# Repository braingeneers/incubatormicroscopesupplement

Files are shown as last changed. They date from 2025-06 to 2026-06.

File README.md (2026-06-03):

# incubatormicroscopesupplement

Supplemental material for the paper "A Modular In-Incubator Microscope for Longitudinal Live Cell Microscopy" by Drew Ehrlich, Yohei Rosen, Santhosh Arul, John Minnick, Seth Nicholson, Kateryna Voitiuk, Spencer Seiler, Anna Toledo, Samira Vera-Choqqueccota, Neil Doherty Jess Sevetson, Max McGlynn, Kivilcim Doganyigit, Maryam Moarefian, Sri Kurniawan, Mohammed A. Mostajo-Radji, Sofie R. Salama, Ethan Winkler, David Haussler, and Mircea Teodorescu.

## File Reference
CAD/CNC/ - 3D CNC parts for the microscopy system.

CAD/flatparts - CAD files for parts that can be milled on a CNC router

CAD/flatparts - CAD files for completed assemblies to be used as visual aids.

code/ - code for programming and operating the microscope in various configurations as shown in the manuscript

data/ - contains the source data for the thermal validation experiment described in Section 2.2.1 of the manuscript

The images for some of the experiments shown in the main manuscript can be found in a OSF repository at: https://osf.io/6wq7r

The contents of this repository are licensed under the Creative Commons CC BY NC license. More information here: https://creativecommons.org/licenses/by-nc/4.0/

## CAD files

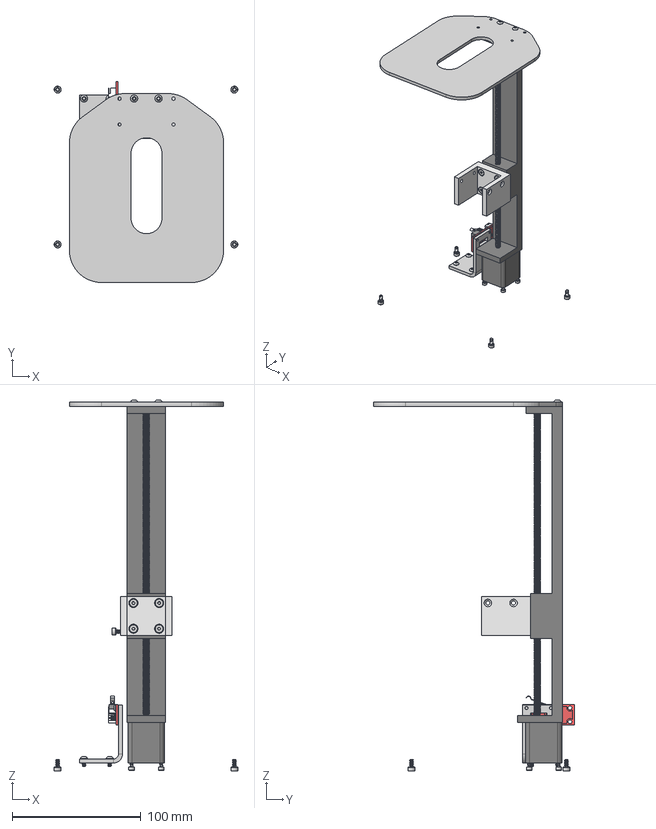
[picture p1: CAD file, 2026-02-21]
CAD/assemblies/zframeassembly.step
143.0 x 156.4 x 288.7 mm
6627T37_Position-Control DC Motor
97783A150_Fast-Travel Ultra-Precision Lead Screw x 3
91290A055_Black-Oxide Alloy Steel Socket Head Screw x 4
rail to alvium adapter 8mm base
Limit_switch
2cl_flou_assembly_topplate_fanct__1_ v2
91290A111_Black-Oxide Alloy Steel Socket Head Screw x 4
92095A181_Button Head Hex Drive Screw x 2
frameassem_1
L_endstopholder_zone (1)
92095A471_Button Head Hex Drive Screw x 2
92095A179_Button Head Hex Drive Screw x 4
91290A120_Black-Oxide Alloy Steel Socket Head Screw
92125A128_18-8 Stainless Steel Hex-Drive Flat Head Screw x 4

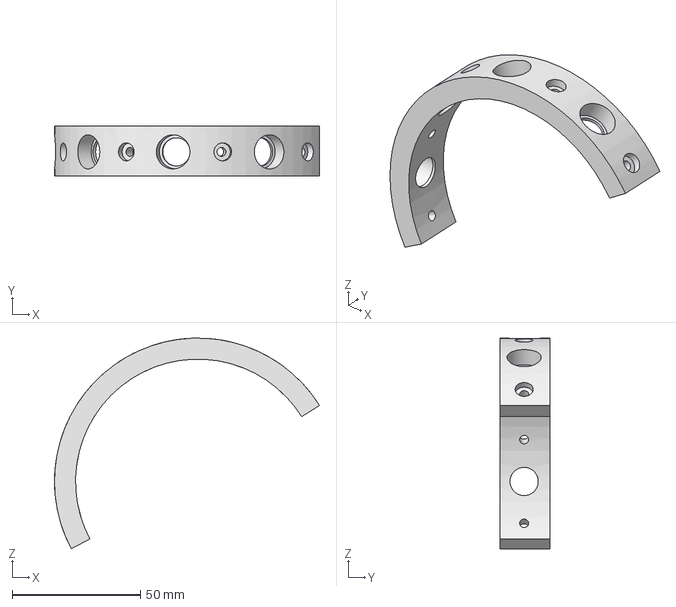
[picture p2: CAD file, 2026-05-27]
CAD/CNC/turret_excitationholder.step
103.2 x 19.4 x 82.0 mm

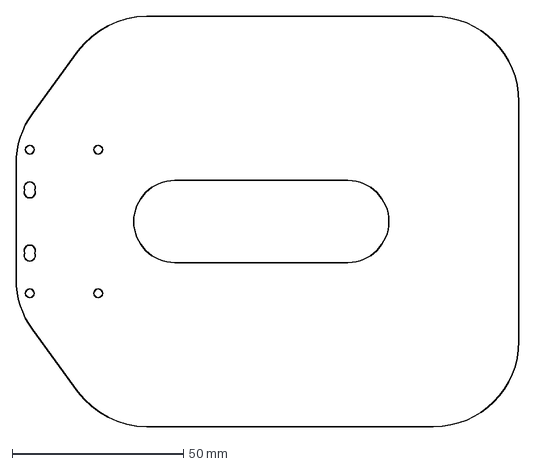
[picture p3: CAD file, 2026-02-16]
CAD/flatparts/flatslot_top_oval.dxf
147.0 x 120.0 mm

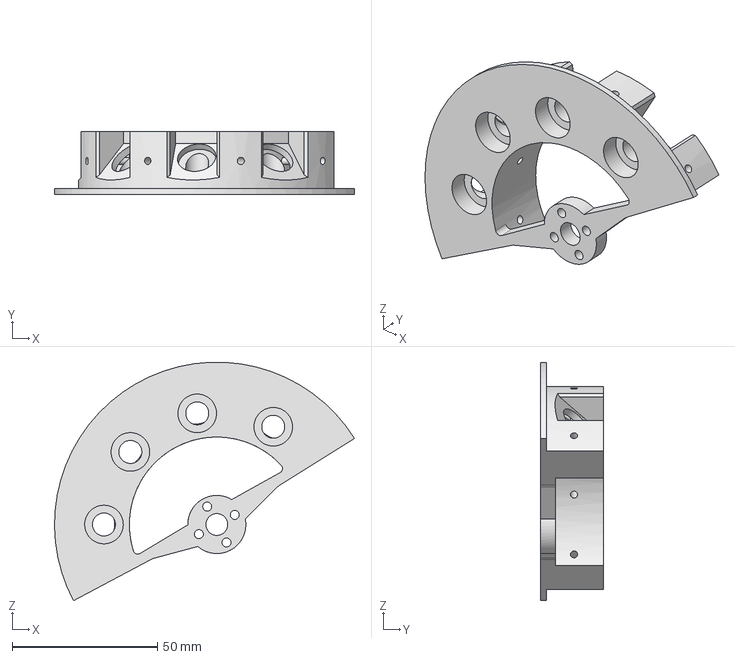
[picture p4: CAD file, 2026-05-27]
CAD/CNC/turret_dichroic_holder.step
103.2 x 21.5 x 82.0 mm

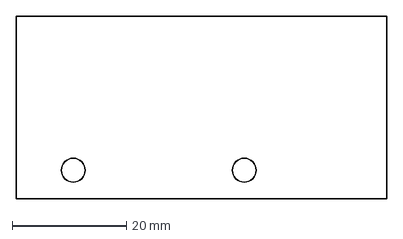
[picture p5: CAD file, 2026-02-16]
CAD/flatparts/endstop_hitter_long_xyz.dxf
65.0 x 32.0 mm

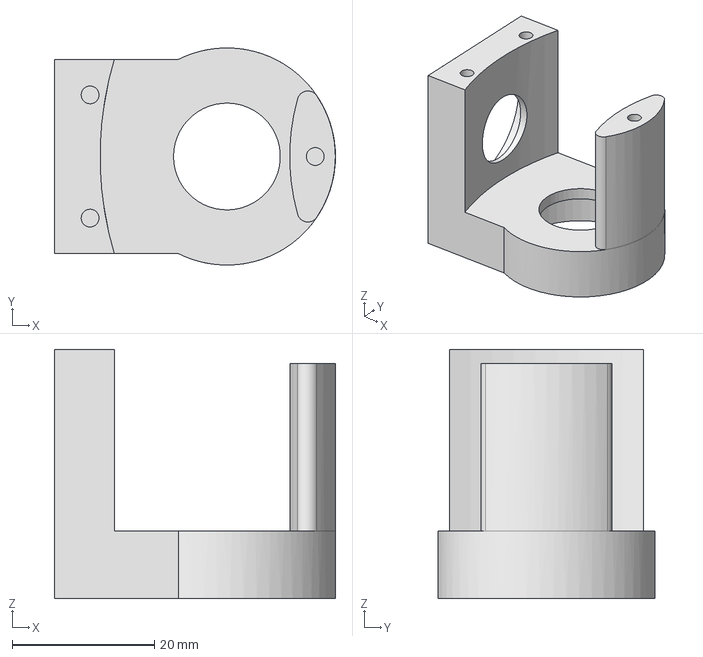
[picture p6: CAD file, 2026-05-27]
CAD/CNC/turret_outer_top_v2.step
39.5 x 30.5 x 35.0 mm

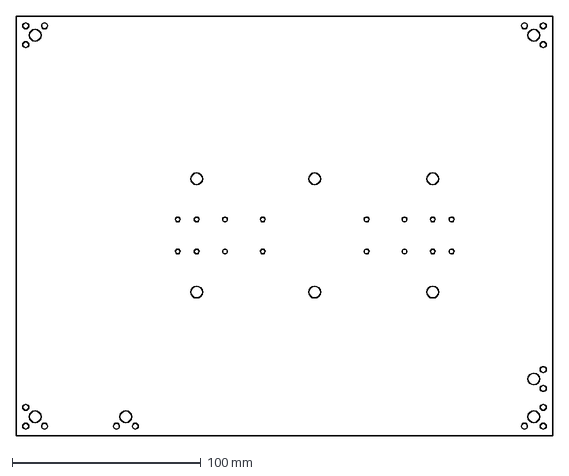
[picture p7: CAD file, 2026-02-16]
CAD/flatparts/bigbase_xyz.dxf
284.0 x 222.0 mm

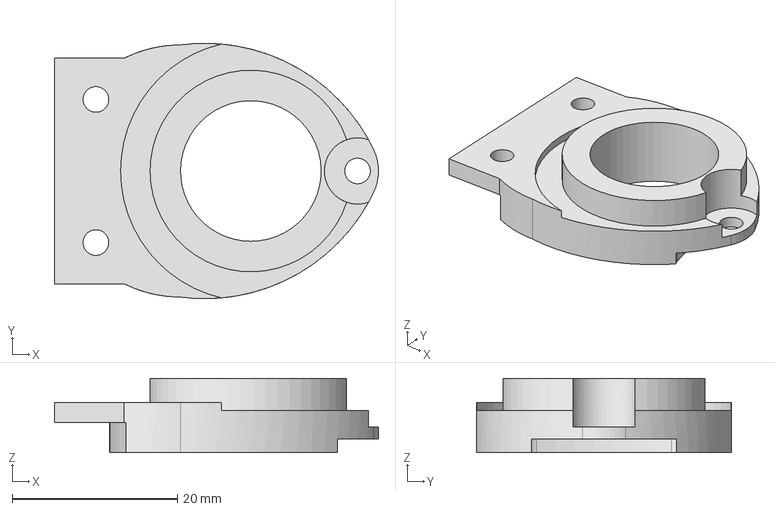
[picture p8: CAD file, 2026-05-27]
CAD/CNC/rotary_filter_barrel_bottom_v2.step
39.2 x 30.9 x 8.99 mm

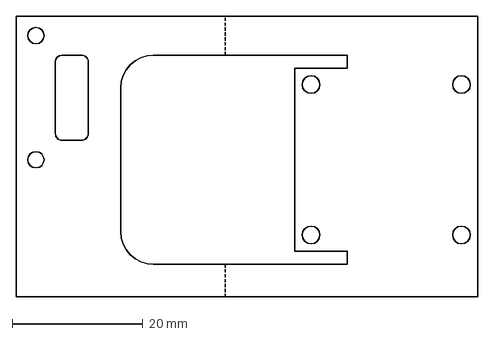
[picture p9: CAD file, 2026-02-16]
CAD/flatparts/xyz_end_218_rev.dxf
70.6 x 43.0 mm

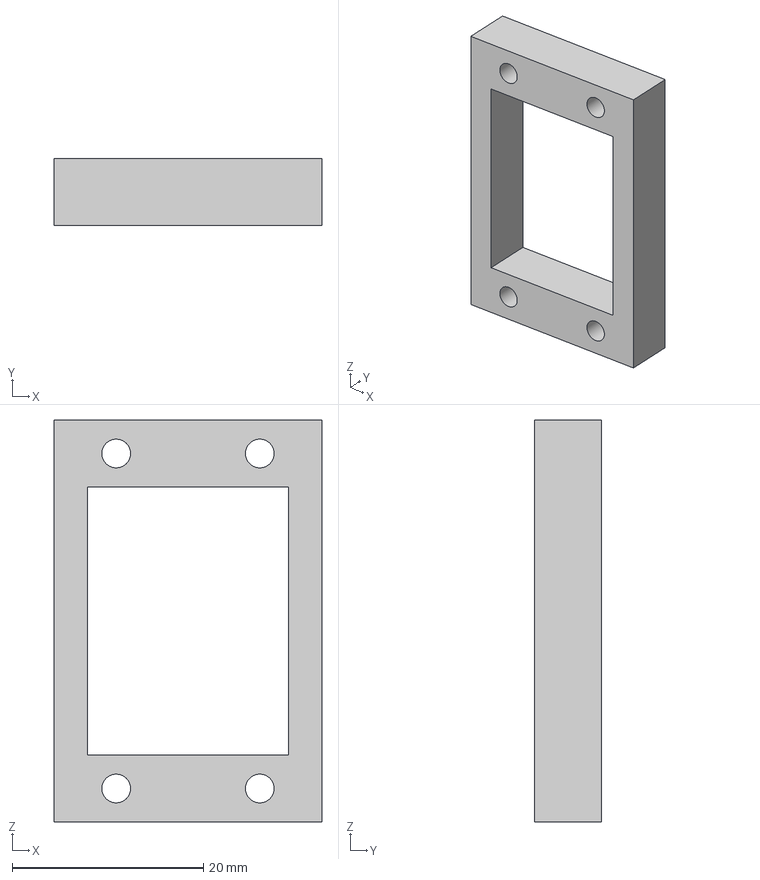
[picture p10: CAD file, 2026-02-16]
CAD/CNC/booster7mm.step
28.0 x 7.00 x 42.0 mm

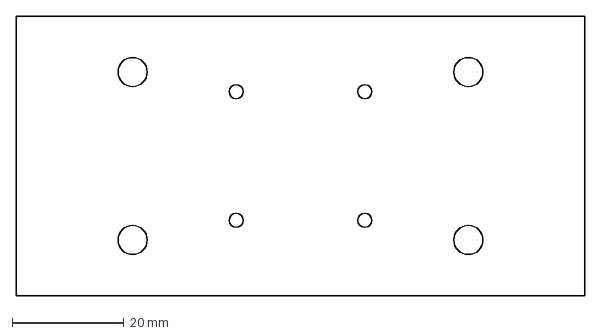
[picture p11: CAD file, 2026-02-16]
CAD/flatparts/midtop_longer_countersink_xyz.dxf
101.6 x 50.0 mm

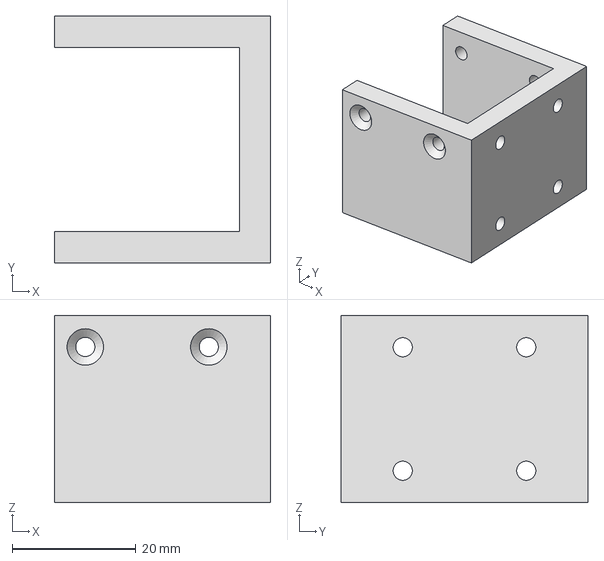
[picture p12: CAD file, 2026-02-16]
CAD/CNC/U_rail to alvium adapter.stp
35.0 x 40.0 x 30.3 mm

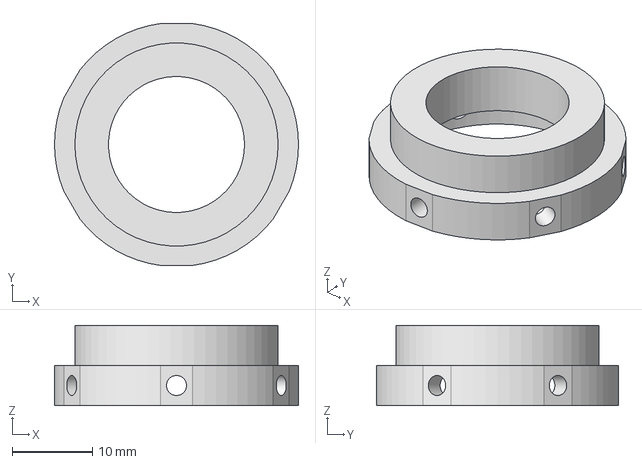
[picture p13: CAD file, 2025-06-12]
CAD/CNC/rotator to c-mount.stp
30.5 x 30.2 x 10.0 mm

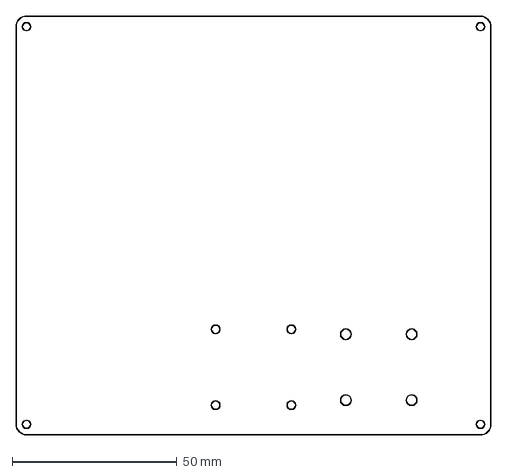
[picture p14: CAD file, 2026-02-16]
CAD/flatparts/microscope_base_z.dxf
144.1 x 127.0 mm

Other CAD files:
CAD/flatparts/frame_top_xyz.dwg
CAD/flatparts/midbot_countersink_xyz.dxf
CAD/flatparts/cam_to_turner_servo.dwg
CAD/flatparts/endstophitter_short_xyz.dxf
CAD/flatparts/endstopholder_Z.dxf
CAD/flatparts/xyz_frame_top_turner.dwg

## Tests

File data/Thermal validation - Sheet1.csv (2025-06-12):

reader date | reader time | interval | Servo | Ambient | Camera | Dish | unit
6/4/2025 0:57:57 | 0:57:57 | 5s | 38.7 | 33.8 | 44.1 | 25.2 | C
6/4/2025 0:58:02 | 0:58:02 | 5s | 38.7 | 33.8 | 44.1 | 25.2 | C
6/4/2025 0:58:07 | 0:58:07 | 5s | 38.7 | 33.8 | 44.1 | 25.2 | C
6/4/2025 0:58:12 | 0:58:12 | 5s | 38.7 | 33.8 | 44.1 | 25.8 | C
6/4/2025 0:58:17 | 0:58:17 | 5s | 38.7 | 34.4 | 44.1 | 25.8 | C
6/4/2025 0:58:22 | 0:58:22 | 5s | 38.7 | 34.4 | 44.1 | 25.8 | C
6/4/2025 0:58:27 | 0:58:27 | 5s | 38.7 | 34.4 | 44.1 | 25.8 | C
6/4/2025 0:58:32 | 0:58:32 | 5s | 38.7 | 34.4 | 44.1 | 25.8 | C
6/4/2025 0:58:37 | 0:58:37 | 5s | 38.7 | 34.4 | 44.1 | 25.9 | C
6/4/2025 0:58:42 | 0:58:42 | 5s | 38.7 | 34.6 | 44.1 | 25.9 | C
6/4/2025 0:58:47 | 0:58:47 | 5s | 38.7 | 34.6 | 44.1 | 26.5 | C
6/4/2025 0:58:52 | 0:58:52 | 5s | 38.7 | 34.6 | 44.1 | 26.5 | C
6/4/2025 0:58:57 | 0:58:57 | 5s | 38.7 | 34.7 | 44.1 | 26.5 | C
6/4/2025 0:59:02 | 0:59:02 | 5s | 38.7 | 34.7 | 44.1 | 26.5 | C
6/4/2025 0:59:07 | 0:59:07 | 5s | 38.7 | 34.7 | 44.1 | 26.5 | C
6/4/2025 0:59:12 | 0:59:12 | 5s | 38.7 | 35.2 | 44.1 | 26.7 | C
6/4/2025 0:59:17 | 0:59:17 | 5s | 38.7 | 35.2 | 44.1 | 26.7 | C
6/4/2025 0:59:22 | 0:59:22 | 5s | 38.7 | 35.2 | 44.1 | 26.7 | C
6/4/2025 0:59:27 | 0:59:27 | 5s | 38.7 | 35.2 | 44.1 | 26.8 | C
6/4/2025 0:59:32 | 0:59:32 | 5s | 38.7 | 35.2 | 44.1 | 27.3 | C
6/4/2025 0:59:37 | 0:59:37 | 5s | 38.7 | 35.2 | 44.1 | 27.3 | C
6/4/2025 0:59:42 | 0:59:42 | 5s | 38.7 | 35.2 | 44.1 | 27.3 | C
6/4/2025 0:59:47 | 0:59:47 | 5s | 38.7 | 35.2 | 44.1 | 27.3 | C
6/4/2025 0:59:52 | 0:59:52 | 5s | 38.7 | 35.2 | 44.1 | 27.3 | C
6/4/2025 0:59:57 | 0:59:57 | 5s | 38.7 | 35.3 | 44.2 | 27.4 | C
6/4/2025 1:00:02 | 1:00:02 | 5s | 38.7 | 35.3 | 44.2 | 27.4 | C
6/4/2025 1:00:07 | 1:00:07 | 5s | 38.7 | 35.3 | 44.2 | 27.4 | C
6/4/2025 1:00:12 | 1:00:12 | 5s | 38.7 | 35.3 | 44.2 | 27.6 | C
6/4/2025 1:00:17 | 1:00:17 | 5s | 38.7 | 35.3 | 44.2 | 27.6 | C
6/4/2025 1:00:22 | 1:00:22 | 5s | 38.7 | 35.3 | 44.2 | 27.6 | C
6/4/2025 1:00:27 | 1:00:27 | 5s | 38.8 | 35.4 | 44.2 | 27.7 | C
6/4/2025 1:00:32 | 1:00:32 | 5s | 38.8 | 35.4 | 44.2 | 27.7 | C
6/4/2025 1:00:37 | 1:00:37 | 5s | 38.8 | 35.4 | 44.2 | 27.7 | C
6/4/2025 1:00:42 | 1:00:42 | 5s | 38.8 | 35.4 | 44.2 | 27.8 | C
6/4/2025 1:00:47 | 1:00:47 | 5s | 38.8 | 35.5 | 44.2 | 27.8 | C
6/4/2025 1:00:52 | 1:00:52 | 5s | 38.8 | 35.5 | 44.2 | 27.8 | C
6/4/2025 1:00:57 | 1:00:57 | 5s | 38.8 | 35.6 | 44.2 | 28 | C
6/4/2025 1:01:02 | 1:01:02 | 5s | 38.8 | 35.6 | 44.2 | 28 | C
6/4/2025 1:01:07 | 1:01:07 | 5s | 38.8 | 35.6 | 44.2 | 28 | C
6/4/2025 1:01:12 | 1:01:12 | 5s | 38.8 | 35.7 | 44.2 | 28.1 | C
6/4/2025 1:01:17 | 1:01:17 | 5s | 38.8 | 35.7 | 44.2 | 28.1 | C
6/4/2025 1:01:22 | 1:01:22 | 5s | 38.8 | 35.7 | 44.2 | 28.1 | C
6/4/2025 1:01:27 | 1:01:27 | 5s | 38.8 | 35.7 | 44.2 | 28.2 | C
6/4/2025 1:01:32 | 1:01:32 | 5s | 38.8 | 35.7 | 44.3 | 28.8 | C
6/4/2025 1:01:37 | 1:01:37 | 5s | 38.8 | 35.8 | 44.3 | 28.8 | C
6/4/2025 1:01:42 | 1:01:42 | 5s | 38.8 | 35.8 | 44.3 | 28.8 | C
6/4/2025 1:01:47 | 1:01:47 | 5s | 38.8 | 35.8 | 44.3 | 28.8 | C
6/4/2025 1:01:52 | 1:01:52 | 5s | 38.9 | 35.8 | 44.3 | 28.8 | C
6/4/2025 1:01:57 | 1:01:57 | 5s | 38.9 | 35.8 | 44.3 | 28.9 | C
6/4/2025 1:02:02 | 1:02:02 | 5s | 38.9 | 35.9 | 44.3 | 28.9 | C
6/4/2025 1:02:07 | 1:02:07 | 5s | 38.9 | 35.9 | 44.3 | 28.9 | C
6/4/2025 1:02:12 | 1:02:12 | 5s | 38.9 | 35.9 | 44.3 | 29.1 | C
6/4/2025 1:02:17 | 1:02:17 | 5s | 38.9 | 35.9 | 44.3 | 29.1 | C
6/4/2025 1:02:22 | 1:02:22 | 5s | 38.9 | 35.9 | 44.3 | 29.1 | C
6/4/2025 1:02:27 | 1:02:27 | 5s | 38.9 | 36.1 | 44.3 | 29.2 | C
6/4/2025 1:02:32 | 1:02:32 | 5s | 38.9 | 36.1 | 44.3 | 29.2 | C
6/4/2025 1:02:37 | 1:02:37 | 5s | 38.9 | 36.1 | 44.3 | 29.2 | C
6/4/2025 1:02:42 | 1:02:42 | 5s | 38.9 | 36.1 | 44.3 | 29.8 | C
6/4/2025 1:02:47 | 1:02:47 | 5s | 38.9 | 36.1 | 44.3 | 29.8 | C
6/4/2025 1:02:52 | 1:02:52 | 5s | 38.9 | 36.1 | 44.3 | 29.8 | C
6/4/2025 1:02:57 | 1:02:57 | 5s | 38.9 | 36.2 | 44.4 | 29.8 | C
6/4/2025 1:03:02 | 1:03:02 | 5s | 38.9 | 36.2 | 44.4 | 29.8 | C
6/4/2025 1:03:07 | 1:03:07 | 5s | 38.9 | 36.2 | 44.4 | 29.8 | C
6/4/2025 1:03:12 | 1:03:12 | 5s | 38.9 | 36.2 | 44.4 | 29.8 | C
6/4/2025 1:03:17 | 1:03:17 | 5s | 38.9 | 36.2 | 44.4 | 29.9 | C
6/4/2025 1:03:22 | 1:03:22 | 5s | 38.9 | 36.2 | 44.4 | 30 | C
6/4/2025 1:03:27 | 1:03:27 | 5s | 38.9 | 36.2 | 44.4 | 30 | C
6/4/2025 1:03:32 | 1:03:32 | 5s | 39 | 36.3 | 44.4 | 30.1 | C
6/4/2025 1:03:37 | 1:03:37 | 5s | 39 | 36.3 | 44.4 | 30.1 | C
6/4/2025 1:03:42 | 1:03:42 | 5s | 39 | 36.3 | 44.4 | 30.1 | C
6/4/2025 1:03:47 | 1:03:47 | 5s | 39 | 36.3 | 44.4 | 30.2 | C
6/4/2025 1:03:52 | 1:03:52 | 5s | 39 | 36.3 | 44.4 | 30.2 | C
6/4/2025 1:03:57 | 1:03:57 | 5s | 39 | 36.3 | 44.4 | 30.8 | C
6/4/2025 1:04:02 | 1:04:02 | 5s | 39 | 36.4 | 44.4 | 30.8 | C
6/4/2025 1:04:07 | 1:04:07 | 5s | 39 | 36.4 | 44.4 | 30.8 | C
6/4/2025 1:04:12 | 1:04:12 | 5s | 39.1 | 36.4 | 44.4 | 30.8 | C
6/4/2025 1:04:17 | 1:04:17 | 5s | 39.1 | 36.4 | 44.4 | 30.8 | C
6/4/2025 1:04:22 | 1:04:22 | 5s | 39.1 | 36.5 | 44.5 | 30.8 | C
6/4/2025 1:04:27 | 1:04:27 | 5s | 39.1 | 36.5 | 44.5 | 30.8 | C
6/4/2025 1:04:32 | 1:04:32 | 5s | 39.1 | 36.5 | 44.5 | 30.8 | C
6/4/2025 1:04:37 | 1:04:37 | 5s | 39.1 | 36.5 | 44.5 | 30.9 | C
6/4/2025 1:04:42 | 1:04:42 | 5s | 39.1 | 36.5 | 44.5 | 30.9 | C
6/4/2025 1:04:47 | 1:04:47 | 5s | 39.1 | 36.5 | 44.5 | 30.9 | C
6/4/2025 1:04:52 | 1:04:52 | 5s | 39.1 | 36.5 | 44.5 | 30.9 | C
6/4/2025 1:04:57 | 1:04:57 | 5s | 39.1 | 36.6 | 44.5 | 31 | C
6/4/2025 1:05:02 | 1:05:02 | 5s | 39.1 | 36.6 | 44.5 | 31 | C
6/4/2025 1:05:07 | 1:05:07 | 5s | 39.1 | 36.6 | 44.6 | 31 | C
6/4/2025 1:05:12 | 1:05:12 | 5s | 39.1 | 36.6 | 44.6 | 31.1 | C
6/4/2025 1:05:17 | 1:05:17 | 5s | 39.1 | 36.6 | 44.6 | 31.2 | C
6/4/2025 1:05:22 | 1:05:22 | 5s | 39.1 | 36.6 | 44.6 | 31.2 | C
6/4/2025 1:05:27 | 1:05:27 | 5s | 39.1 | 36.6 | 44.6 | 31.2 | C
6/4/2025 1:05:32 | 1:05:32 | 5s | 39.1 | 36.6 | 44.6 | 31.2 | C
6/4/2025 1:05:37 | 1:05:37 | 5s | 39.1 | 36.6 | 44.6 | 31.3 | C
6/4/2025 1:05:42 | 1:05:42 | 5s | 39.2 | 36.6 | 44.6 | 31.3 | C
6/4/2025 1:05:47 | 1:05:47 | 5s | 39.2 | 36.6 | 44.6 | 31.3 | C
6/4/2025 1:05:52 | 1:05:52 | 5s | 39.2 | 36.6 | 44.6 | 31.3 | C
6/4/2025 1:05:57 | 1:05:57 | 5s | 39.2 | 36.6 | 44.6 | 31.4 | C
6/4/2025 1:06:02 | 1:06:02 | 5s | 39.2 | 36.7 | 44.6 | 31.4 | C
6/4/2025 1:06:07 | 1:06:07 | 5s | 39.2 | 36.7 | 44.6 | 31.4 | C
6/4/2025 1:06:12 | 1:06:12 | 5s | 39.2 | 36.7 | 44.6 | 31.5 | C
6/4/2025 1:06:17 | 1:06:17 | 5s | 39.2 | 36.7 | 44.6 | 31.6 | C
6/4/2025 1:06:22 | 1:06:22 | 5s | 39.2 | 36.7 | 44.6 | 31.6 | C
6/4/2025 1:06:27 | 1:06:27 | 5s | 39.2 | 36.7 | 44.7 | 31.6 | C
6/4/2025 1:06:32 | 1:06:32 | 5s | 39.2 | 36.7 | 44.7 | 31.7 | C
6/4/2025 1:06:37 | 1:06:37 | 5s | 39.2 | 36.7 | 44.7 | 31.7 | C
6/4/2025 1:06:42 | 1:06:42 | 5s | 39.2 | 36.7 | 44.7 | 31.7 | C
6/4/2025 1:06:47 | 1:06:47 | 5s | 39.2 | 36.7 | 44.7 | 31.8 | C
6/4/2025 1:06:52 | 1:06:52 | 5s | 39.2 | 36.7 | 44.7 | 31.8 | C
6/4/2025 1:06:57 | 1:06:57 | 5s | 39.2 | 36.7 | 44.7 | 31.8 | C
6/4/2025 1:07:02 | 1:07:02 | 5s | 39.3 | 36.8 | 44.7 | 31.9 | C
6/4/2025 1:07:07 | 1:07:07 | 5s | 39.3 | 36.8 | 44.7 | 31.9 | C
6/4/2025 1:07:12 | 1:07:12 | 5s | 39.3 | 36.8 | 44.7 | 31.9 | C
6/4/2025 1:07:17 | 1:07:17 | 5s | 39.3 | 36.8 | 44.7 | 31.9 | C
6/4/2025 1:07:22 | 1:07:22 | 5s | 39.3 | 36.8 | 44.7 | 32.1 | C
6/4/2025 1:07:27 | 1:07:27 | 5s | 39.3 | 36.8 | 44.7 | 32.1 | C
6/4/2025 1:07:32 | 1:07:32 | 5s | 39.3 | 36.8 | 44.7 | 32.1 | C
6/4/2025 1:07:37 | 1:07:37 | 5s | 39.3 | 36.8 | 44.7 | 32.2 | C
6/4/2025 1:07:42 | 1:07:42 | 5s | 39.3 | 36.8 | 44.7 | 32.2 | C
6/4/2025 1:07:47 | 1:07:47 | 5s | 39.3 | 36.8 | 44.8 | 32.2 | C
6/4/2025 1:07:52 | 1:07:52 | 5s | 39.3 | 36.8 | 44.8 | 32.3 | C
6/4/2025 1:07:57 | 1:07:57 | 5s | 39.3 | 36.8 | 44.8 | 32.3 | C
6/4/2025 1:08:02 | 1:08:02 | 5s | 39.3 | 36.8 | 44.8 | 32.3 | C
6/4/2025 1:08:07 | 1:08:07 | 5s | 39.3 | 36.8 | 44.8 | 32.4 | C
6/4/2025 1:08:12 | 1:08:12 | 5s | 39.4 | 36.8 | 44.8 | 32.4 | C
6/4/2025 1:08:17 | 1:08:17 | 5s | 39.4 | 36.8 | 44.8 | 32.4 | C
6/4/2025 1:08:22 | 1:08:22 | 5s | 39.4 | 36.8 | 44.8 | 32.6 | C
6/4/2025 1:08:27 | 1:08:27 | 5s | 39.4 | 36.8 | 44.8 | 32.6 | C
6/4/2025 1:08:32 | 1:08:32 | 5s | 39.4 | 36.8 | 44.8 | 32.6 | C
6/4/2025 1:08:37 | 1:08:37 | 5s | 39.4 | 36.9 | 44.8 | 32.6 | C
6/4/2025 1:08:42 | 1:08:42 | 5s | 39.4 | 36.9 | 44.8 | 32.7 | C
6/4/2025 1:08:47 | 1:08:47 | 5s | 39.4 | 36.9 | 44.8 | 32.7 | C
6/4/2025 1:08:52 | 1:08:52 | 5s | 39.4 | 36.9 | 44.8 | 32.7 | C
6/4/2025 1:08:57 | 1:08:57 | 5s | 39.4 | 36.9 | 44.8 | 32.7 | C
6/4/2025 1:09:02 | 1:09:02 | 5s | 39.4 | 36.9 | 44.8 | 32.8 | C
6/4/2025 1:09:07 | 1:09:07 | 5s | 39.4 | 36.9 | 44.8 | 32.8 | C
6/4/2025 1:09:12 | 1:09:12 | 5s | 39.4 | 36.9 | 44.8 | 32.8 | C
6/4/2025 1:09:17 | 1:09:17 | 5s | 39.4 | 36.9 | 44.9 | 32.8 | C
6/4/2025 1:09:22 | 1:09:22 | 5s | 39.5 | 36.9 | 44.9 | 32.9 | C
6/4/2025 1:09:27 | 1:09:27 | 5s | 39.5 | 36.9 | 44.9 | 32.9 | C
6/4/2025 1:09:32 | 1:09:32 | 5s | 39.5 | 36.9 | 44.9 | 32.9 | C
6/4/2025 1:09:37 | 1:09:37 | 5s | 39.5 | 36.9 | 44.9 | 32.9 | C
6/4/2025 1:09:42 | 1:09:42 | 5s | 39.5 | 36.9 | 44.9 | 33.1 | C
6/4/2025 1:09:47 | 1:09:47 | 5s | 39.5 | 36.9 | 44.9 | 33.1 | C
6/4/2025 1:09:52 | 1:09:52 | 5s | 39.5 | 36.9 | 44.9 | 33.1 | C
6/4/2025 1:09:57 | 1:09:57 | 5s | 39.6 | 36.9 | 44.9 | 33.1 | C
6/4/2025 1:10:02 | 1:10:02 | 5s | 39.6 | 36.9 | 44.9 | 33.1 | C
6/4/2025 1:10:07 | 1:10:07 | 5s | 39.6 | 36.9 | 44.9 | 33.2 | C
6/4/2025 1:10:12 | 1:10:12 | 5s | 39.6 | 36.9 | 44.9 | 33.2 | C
6/4/2025 1:10:17 | 1:10:17 | 5s | 39.6 | 36.9 | 44.9 | 33.2 | C
6/4/2025 1:10:22 | 1:10:22 | 5s | 39.6 | 36.9 | 44.9 | 33.2 | C
6/4/2025 1:10:27 | 1:10:27 | 5s | 39.6 | 36.9 | 44.9 | 33.2 | C
6/4/2025 1:10:32 | 1:10:32 | 5s | 39.6 | 36.9 | 44.9 | 33.3 | C
6/4/2025 1:10:37 | 1:10:37 | 5s | 39.6 | 37 | 44.9 | 33.3 | C
6/4/2025 1:10:42 | 1:10:42 | 5s | 39.6 | 37 | 44.9 | 33.3 | C
6/4/2025 1:10:47 | 1:10:47 | 5s | 39.6 | 37 | 45 | 33.4 | C
6/4/2025 1:10:52 | 1:10:52 | 5s | 39.6 | 37 | 45 | 33.4 | C
6/4/2025 1:10:57 | 1:10:57 | 5s | 39.6 | 37 | 45 | 33.5 | C
6/4/2025 1:11:02 | 1:11:02 | 5s | 39.6 | 37 | 45 | 33.5 | C
6/4/2025 1:11:07 | 1:11:07 | 5s | 39.6 | 37 | 45 | 33.5 | C
6/4/2025 1:11:12 | 1:11:12 | 5s | 39.7 | 37 | 45 | 33.5 | C
6/4/2025 1:11:17 | 1:11:17 | 5s | 39.7 | 37 | 45 | 33.5 | C
6/4/2025 1:11:22 | 1:11:22 | 5s | 39.7 | 37 | 45 | 33.5 | C
6/4/2025 1:11:27 | 1:11:27 | 5s | 39.7 | 37 | 45 | 33.6 | C
6/4/2025 1:11:32 | 1:11:32 | 5s | 39.7 | 37 | 45 | 33.6 | C
6/4/2025 1:11:37 | 1:11:37 | 5s | 39.7 | 37 | 45.1 | 33.6 | C
6/4/2025 1:11:42 | 1:11:42 | 5s | 39.7 | 37 | 45.1 | 33.6 | C
6/4/2025 1:11:47 | 1:11:47 | 5s | 39.7 | 37 | 45.1 | 33.7 | C
6/4/2025 1:11:52 | 1:11:52 | 5s | 39.7 | 37 | 45.1 | 33.7 | C
6/4/2025 1:11:57 | 1:11:57 | 5s | 39.7 | 37 | 45.1 | 33.8 | C
6/4/2025 1:12:02 | 1:12:02 | 5s | 39.7 | 37 | 45.1 | 33.8 | C
6/4/2025 1:12:07 | 1:12:07 | 5s | 39.7 | 37 | 45.1 | 33.8 | C
6/4/2025 1:12:12 | 1:12:12 | 5s | 39.7 | 37.1 | 45.1 | 33.8 | C
6/4/2025 1:12:17 | 1:12:17 | 5s | 39.7 | 37.1 | 45.1 | 33.8 | C
6/4/2025 1:12:22 | 1:12:22 | 5s | 39.7 | 37.1 | 45.1 | 33.8 | C
6/4/2025 1:12:27 | 1:12:27 | 5s | 39.7 | 37.1 | 45.1 | 33.9 | C
6/4/2025 1:12:32 | 1:12:32 | 5s | 39.7 | 37.1 | 45.1 | 33.9 | C
6/4/2025 1:12:37 | 1:12:37 | 5s | 39.7 | 37.1 | 45.1 | 33.9 | C
6/4/2025 1:12:42 | 1:12:42 | 5s | 39.8 | 37.1 | 45.1 | 33.9 | C
6/4/2025 1:12:47 | 1:12:47 | 5s | 39.8 | 37.1 | 45.1 | 33.9 | C
6/4/2025 1:12:52 | 1:12:52 | 5s | 39.8 | 37.1 | 45.1 | 33.9 | C
6/4/2025 1:12:57 | 1:12:57 | 5s | 39.8 | 37.1 | 45.1 | 33.9 | C
6/4/2025 1:13:02 | 1:13:02 | 5s | 39.8 | 37.1 | 45.1 | 34.1 | C
6/4/2025 1:13:07 | 1:13:07 | 5s | 39.8 | 37.1 | 45.2 | 34.1 | C
6/4/2025 1:13:12 | 1:13:12 | 5s | 39.8 | 37.1 | 45.2 | 34.1 | C
6/4/2025 1:13:17 | 1:13:17 | 5s | 39.8 | 37.1 | 45.2 | 34.1 | C
6/4/2025 1:13:22 | 1:13:22 | 5s | 39.8 | 37.1 | 45.2 | 34.1 | C
6/4/2025 1:13:27 | 1:13:27 | 5s | 39.8 | 37.1 | 45.2 | 34.1 | C
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

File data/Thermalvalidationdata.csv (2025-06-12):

reader date | reader time | interval | Servo | Ambient | Camera | Dish | unit
6/4/2025 0:57:57 | 0:57:57 | 5s | 38.7 | 33.8 | 44.1 | 25.2 | C
6/4/2025 0:58:02 | 0:58:02 | 5s | 38.7 | 33.8 | 44.1 | 25.2 | C
6/4/2025 0:58:07 | 0:58:07 | 5s | 38.7 | 33.8 | 44.1 | 25.2 | C
6/4/2025 0:58:12 | 0:58:12 | 5s | 38.7 | 33.8 | 44.1 | 25.8 | C
6/4/2025 0:58:17 | 0:58:17 | 5s | 38.7 | 34.4 | 44.1 | 25.8 | C
6/4/2025 0:58:22 | 0:58:22 | 5s | 38.7 | 34.4 | 44.1 | 25.8 | C
6/4/2025 0:58:27 | 0:58:27 | 5s | 38.7 | 34.4 | 44.1 | 25.8 | C
6/4/2025 0:58:32 | 0:58:32 | 5s | 38.7 | 34.4 | 44.1 | 25.8 | C
6/4/2025 0:58:37 | 0:58:37 | 5s | 38.7 | 34.4 | 44.1 | 25.9 | C
6/4/2025 0:58:42 | 0:58:42 | 5s | 38.7 | 34.6 | 44.1 | 25.9 | C
6/4/2025 0:58:47 | 0:58:47 | 5s | 38.7 | 34.6 | 44.1 | 26.5 | C
6/4/2025 0:58:52 | 0:58:52 | 5s | 38.7 | 34.6 | 44.1 | 26.5 | C
6/4/2025 0:58:57 | 0:58:57 | 5s | 38.7 | 34.7 | 44.1 | 26.5 | C
6/4/2025 0:59:02 | 0:59:02 | 5s | 38.7 | 34.7 | 44.1 | 26.5 | C
6/4/2025 0:59:07 | 0:59:07 | 5s | 38.7 | 34.7 | 44.1 | 26.5 | C
6/4/2025 0:59:12 | 0:59:12 | 5s | 38.7 | 35.2 | 44.1 | 26.7 | C
6/4/2025 0:59:17 | 0:59:17 | 5s | 38.7 | 35.2 | 44.1 | 26.7 | C
6/4/2025 0:59:22 | 0:59:22 | 5s | 38.7 | 35.2 | 44.1 | 26.7 | C
6/4/2025 0:59:27 | 0:59:27 | 5s | 38.7 | 35.2 | 44.1 | 26.8 | C
6/4/2025 0:59:32 | 0:59:32 | 5s | 38.7 | 35.2 | 44.1 | 27.3 | C
6/4/2025 0:59:37 | 0:59:37 | 5s | 38.7 | 35.2 | 44.1 | 27.3 | C
6/4/2025 0:59:42 | 0:59:42 | 5s | 38.7 | 35.2 | 44.1 | 27.3 | C
6/4/2025 0:59:47 | 0:59:47 | 5s | 38.7 | 35.2 | 44.1 | 27.3 | C
6/4/2025 0:59:52 | 0:59:52 | 5s | 38.7 | 35.2 | 44.1 | 27.3 | C
6/4/2025 0:59:57 | 0:59:57 | 5s | 38.7 | 35.3 | 44.2 | 27.4 | C
6/4/2025 1:00:02 | 1:00:02 | 5s | 38.7 | 35.3 | 44.2 | 27.4 | C
6/4/2025 1:00:07 | 1:00:07 | 5s | 38.7 | 35.3 | 44.2 | 27.4 | C
6/4/2025 1:00:12 | 1:00:12 | 5s | 38.7 | 35.3 | 44.2 | 27.6 | C
6/4/2025 1:00:17 | 1:00:17 | 5s | 38.7 | 35.3 | 44.2 | 27.6 | C
6/4/2025 1:00:22 | 1:00:22 | 5s | 38.7 | 35.3 | 44.2 | 27.6 | C
6/4/2025 1:00:27 | 1:00:27 | 5s | 38.8 | 35.4 | 44.2 | 27.7 | C
6/4/2025 1:00:32 | 1:00:32 | 5s | 38.8 | 35.4 | 44.2 | 27.7 | C
6/4/2025 1:00:37 | 1:00:37 | 5s | 38.8 | 35.4 | 44.2 | 27.7 | C
6/4/2025 1:00:42 | 1:00:42 | 5s | 38.8 | 35.4 | 44.2 | 27.8 | C
6/4/2025 1:00:47 | 1:00:47 | 5s | 38.8 | 35.5 | 44.2 | 27.8 | C
6/4/2025 1:00:52 | 1:00:52 | 5s | 38.8 | 35.5 | 44.2 | 27.8 | C
6/4/2025 1:00:57 | 1:00:57 | 5s | 38.8 | 35.6 | 44.2 | 28 | C
6/4/2025 1:01:02 | 1:01:02 | 5s | 38.8 | 35.6 | 44.2 | 28 | C
6/4/2025 1:01:07 | 1:01:07 | 5s | 38.8 | 35.6 | 44.2 | 28 | C
6/4/2025 1:01:12 | 1:01:12 | 5s | 38.8 | 35.7 | 44.2 | 28.1 | C
6/4/2025 1:01:17 | 1:01:17 | 5s | 38.8 | 35.7 | 44.2 | 28.1 | C
6/4/2025 1:01:22 | 1:01:22 | 5s | 38.8 | 35.7 | 44.2 | 28.1 | C
6/4/2025 1:01:27 | 1:01:27 | 5s | 38.8 | 35.7 | 44.2 | 28.2 | C
6/4/2025 1:01:32 | 1:01:32 | 5s | 38.8 | 35.7 | 44.3 | 28.8 | C
6/4/2025 1:01:37 | 1:01:37 | 5s | 38.8 | 35.8 | 44.3 | 28.8 | C
6/4/2025 1:01:42 | 1:01:42 | 5s | 38.8 | 35.8 | 44.3 | 28.8 | C
6/4/2025 1:01:47 | 1:01:47 | 5s | 38.8 | 35.8 | 44.3 | 28.8 | C
6/4/2025 1:01:52 | 1:01:52 | 5s | 38.9 | 35.8 | 44.3 | 28.8 | C
6/4/2025 1:01:57 | 1:01:57 | 5s | 38.9 | 35.8 | 44.3 | 28.9 | C
6/4/2025 1:02:02 | 1:02:02 | 5s | 38.9 | 35.9 | 44.3 | 28.9 | C
6/4/2025 1:02:07 | 1:02:07 | 5s | 38.9 | 35.9 | 44.3 | 28.9 | C
6/4/2025 1:02:12 | 1:02:12 | 5s | 38.9 | 35.9 | 44.3 | 29.1 | C
6/4/2025 1:02:17 | 1:02:17 | 5s | 38.9 | 35.9 | 44.3 | 29.1 | C
6/4/2025 1:02:22 | 1:02:22 | 5s | 38.9 | 35.9 | 44.3 | 29.1 | C
6/4/2025 1:02:27 | 1:02:27 | 5s | 38.9 | 36.1 | 44.3 | 29.2 | C
6/4/2025 1:02:32 | 1:02:32 | 5s | 38.9 | 36.1 | 44.3 | 29.2 | C
6/4/2025 1:02:37 | 1:02:37 | 5s | 38.9 | 36.1 | 44.3 | 29.2 | C
6/4/2025 1:02:42 | 1:02:42 | 5s | 38.9 | 36.1 | 44.3 | 29.8 | C
6/4/2025 1:02:47 | 1:02:47 | 5s | 38.9 | 36.1 | 44.3 | 29.8 | C
6/4/2025 1:02:52 | 1:02:52 | 5s | 38.9 | 36.1 | 44.3 | 29.8 | C
6/4/2025 1:02:57 | 1:02:57 | 5s | 38.9 | 36.2 | 44.4 | 29.8 | C
6/4/2025 1:03:02 | 1:03:02 | 5s | 38.9 | 36.2 | 44.4 | 29.8 | C
6/4/2025 1:03:07 | 1:03:07 | 5s | 38.9 | 36.2 | 44.4 | 29.8 | C
6/4/2025 1:03:12 | 1:03:12 | 5s | 38.9 | 36.2 | 44.4 | 29.8 | C
6/4/2025 1:03:17 | 1:03:17 | 5s | 38.9 | 36.2 | 44.4 | 29.9 | C
6/4/2025 1:03:22 | 1:03:22 | 5s | 38.9 | 36.2 | 44.4 | 30 | C
6/4/2025 1:03:27 | 1:03:27 | 5s | 38.9 | 36.2 | 44.4 | 30 | C
6/4/2025 1:03:32 | 1:03:32 | 5s | 39 | 36.3 | 44.4 | 30.1 | C
6/4/2025 1:03:37 | 1:03:37 | 5s | 39 | 36.3 | 44.4 | 30.1 | C
6/4/2025 1:03:42 | 1:03:42 | 5s | 39 | 36.3 | 44.4 | 30.1 | C
6/4/2025 1:03:47 | 1:03:47 | 5s | 39 | 36.3 | 44.4 | 30.2 | C
6/4/2025 1:03:52 | 1:03:52 | 5s | 39 | 36.3 | 44.4 | 30.2 | C
6/4/2025 1:03:57 | 1:03:57 | 5s | 39 | 36.3 | 44.4 | 30.8 | C
6/4/2025 1:04:02 | 1:04:02 | 5s | 39 | 36.4 | 44.4 | 30.8 | C
6/4/2025 1:04:07 | 1:04:07 | 5s | 39 | 36.4 | 44.4 | 30.8 | C
6/4/2025 1:04:12 | 1:04:12 | 5s | 39.1 | 36.4 | 44.4 | 30.8 | C
6/4/2025 1:04:17 | 1:04:17 | 5s | 39.1 | 36.4 | 44.4 | 30.8 | C
6/4/2025 1:04:22 | 1:04:22 | 5s | 39.1 | 36.5 | 44.5 | 30.8 | C
6/4/2025 1:04:27 | 1:04:27 | 5s | 39.1 | 36.5 | 44.5 | 30.8 | C
6/4/2025 1:04:32 | 1:04:32 | 5s | 39.1 | 36.5 | 44.5 | 30.8 | C
6/4/2025 1:04:37 | 1:04:37 | 5s | 39.1 | 36.5 | 44.5 | 30.9 | C
6/4/2025 1:04:42 | 1:04:42 | 5s | 39.1 | 36.5 | 44.5 | 30.9 | C
6/4/2025 1:04:47 | 1:04:47 | 5s | 39.1 | 36.5 | 44.5 | 30.9 | C
6/4/2025 1:04:52 | 1:04:52 | 5s | 39.1 | 36.5 | 44.5 | 30.9 | C
6/4/2025 1:04:57 | 1:04:57 | 5s | 39.1 | 36.6 | 44.5 | 31 | C
6/4/2025 1:05:02 | 1:05:02 | 5s | 39.1 | 36.6 | 44.5 | 31 | C
6/4/2025 1:05:07 | 1:05:07 | 5s | 39.1 | 36.6 | 44.6 | 31 | C
6/4/2025 1:05:12 | 1:05:12 | 5s | 39.1 | 36.6 | 44.6 | 31.1 | C
6/4/2025 1:05:17 | 1:05:17 | 5s | 39.1 | 36.6 | 44.6 | 31.2 | C
6/4/2025 1:05:22 | 1:05:22 | 5s | 39.1 | 36.6 | 44.6 | 31.2 | C
6/4/2025 1:05:27 | 1:05:27 | 5s | 39.1 | 36.6 | 44.6 | 31.2 | C
6/4/2025 1:05:32 | 1:05:32 | 5s | 39.1 | 36.6 | 44.6 | 31.2 | C
6/4/2025 1:05:37 | 1:05:37 | 5s | 39.1 | 36.6 | 44.6 | 31.3 | C
6/4/2025 1:05:42 | 1:05:42 | 5s | 39.2 | 36.6 | 44.6 | 31.3 | C
6/4/2025 1:05:47 | 1:05:47 | 5s | 39.2 | 36.6 | 44.6 | 31.3 | C
6/4/2025 1:05:52 | 1:05:52 | 5s | 39.2 | 36.6 | 44.6 | 31.3 | C
6/4/2025 1:05:57 | 1:05:57 | 5s | 39.2 | 36.6 | 44.6 | 31.4 | C
6/4/2025 1:06:02 | 1:06:02 | 5s | 39.2 | 36.7 | 44.6 | 31.4 | C
6/4/2025 1:06:07 | 1:06:07 | 5s | 39.2 | 36.7 | 44.6 | 31.4 | C
6/4/2025 1:06:12 | 1:06:12 | 5s | 39.2 | 36.7 | 44.6 | 31.5 | C
6/4/2025 1:06:17 | 1:06:17 | 5s | 39.2 | 36.7 | 44.6 | 31.6 | C
6/4/2025 1:06:22 | 1:06:22 | 5s | 39.2 | 36.7 | 44.6 | 31.6 | C
6/4/2025 1:06:27 | 1:06:27 | 5s | 39.2 | 36.7 | 44.7 | 31.6 | C
6/4/2025 1:06:32 | 1:06:32 | 5s | 39.2 | 36.7 | 44.7 | 31.7 | C
6/4/2025 1:06:37 | 1:06:37 | 5s | 39.2 | 36.7 | 44.7 | 31.7 | C
6/4/2025 1:06:42 | 1:06:42 | 5s | 39.2 | 36.7 | 44.7 | 31.7 | C
6/4/2025 1:06:47 | 1:06:47 | 5s | 39.2 | 36.7 | 44.7 | 31.8 | C
6/4/2025 1:06:52 | 1:06:52 | 5s | 39.2 | 36.7 | 44.7 | 31.8 | C
6/4/2025 1:06:57 | 1:06:57 | 5s | 39.2 | 36.7 | 44.7 | 31.8 | C
6/4/2025 1:07:02 | 1:07:02 | 5s | 39.3 | 36.8 | 44.7 | 31.9 | C
6/4/2025 1:07:07 | 1:07:07 | 5s | 39.3 | 36.8 | 44.7 | 31.9 | C
6/4/2025 1:07:12 | 1:07:12 | 5s | 39.3 | 36.8 | 44.7 | 31.9 | C
6/4/2025 1:07:17 | 1:07:17 | 5s | 39.3 | 36.8 | 44.7 | 31.9 | C
6/4/2025 1:07:22 | 1:07:22 | 5s | 39.3 | 36.8 | 44.7 | 32.1 | C
6/4/2025 1:07:27 | 1:07:27 | 5s | 39.3 | 36.8 | 44.7 | 32.1 | C
6/4/2025 1:07:32 | 1:07:32 | 5s | 39.3 | 36.8 | 44.7 | 32.1 | C
6/4/2025 1:07:37 | 1:07:37 | 5s | 39.3 | 36.8 | 44.7 | 32.2 | C
6/4/2025 1:07:42 | 1:07:42 | 5s | 39.3 | 36.8 | 44.7 | 32.2 | C
6/4/2025 1:07:47 | 1:07:47 | 5s | 39.3 | 36.8 | 44.8 | 32.2 | C
6/4/2025 1:07:52 | 1:07:52 | 5s | 39.3 | 36.8 | 44.8 | 32.3 | C
6/4/2025 1:07:57 | 1:07:57 | 5s | 39.3 | 36.8 | 44.8 | 32.3 | C
6/4/2025 1:08:02 | 1:08:02 | 5s | 39.3 | 36.8 | 44.8 | 32.3 | C
6/4/2025 1:08:07 | 1:08:07 | 5s | 39.3 | 36.8 | 44.8 | 32.4 | C
6/4/2025 1:08:12 | 1:08:12 | 5s | 39.4 | 36.8 | 44.8 | 32.4 | C
6/4/2025 1:08:17 | 1:08:17 | 5s | 39.4 | 36.8 | 44.8 | 32.4 | C
6/4/2025 1:08:22 | 1:08:22 | 5s | 39.4 | 36.8 | 44.8 | 32.6 | C
6/4/2025 1:08:27 | 1:08:27 | 5s | 39.4 | 36.8 | 44.8 | 32.6 | C
6/4/2025 1:08:32 | 1:08:32 | 5s | 39.4 | 36.8 | 44.8 | 32.6 | C
6/4/2025 1:08:37 | 1:08:37 | 5s | 39.4 | 36.9 | 44.8 | 32.6 | C
6/4/2025 1:08:42 | 1:08:42 | 5s | 39.4 | 36.9 | 44.8 | 32.7 | C
6/4/2025 1:08:47 | 1:08:47 | 5s | 39.4 | 36.9 | 44.8 | 32.7 | C
6/4/2025 1:08:52 | 1:08:52 | 5s | 39.4 | 36.9 | 44.8 | 32.7 | C
6/4/2025 1:08:57 | 1:08:57 | 5s | 39.4 | 36.9 | 44.8 | 32.7 | C
6/4/2025 1:09:02 | 1:09:02 | 5s | 39.4 | 36.9 | 44.8 | 32.8 | C
6/4/2025 1:09:07 | 1:09:07 | 5s | 39.4 | 36.9 | 44.8 | 32.8 | C
6/4/2025 1:09:12 | 1:09:12 | 5s | 39.4 | 36.9 | 44.8 | 32.8 | C
6/4/2025 1:09:17 | 1:09:17 | 5s | 39.4 | 36.9 | 44.9 | 32.8 | C
6/4/2025 1:09:22 | 1:09:22 | 5s | 39.5 | 36.9 | 44.9 | 32.9 | C
6/4/2025 1:09:27 | 1:09:27 | 5s | 39.5 | 36.9 | 44.9 | 32.9 | C
6/4/2025 1:09:32 | 1:09:32 | 5s | 39.5 | 36.9 | 44.9 | 32.9 | C
6/4/2025 1:09:37 | 1:09:37 | 5s | 39.5 | 36.9 | 44.9 | 32.9 | C
6/4/2025 1:09:42 | 1:09:42 | 5s | 39.5 | 36.9 | 44.9 | 33.1 | C
6/4/2025 1:09:47 | 1:09:47 | 5s | 39.5 | 36.9 | 44.9 | 33.1 | C
6/4/2025 1:09:52 | 1:09:52 | 5s | 39.5 | 36.9 | 44.9 | 33.1 | C
6/4/2025 1:09:57 | 1:09:57 | 5s | 39.6 | 36.9 | 44.9 | 33.1 | C
6/4/2025 1:10:02 | 1:10:02 | 5s | 39.6 | 36.9 | 44.9 | 33.1 | C
6/4/2025 1:10:07 | 1:10:07 | 5s | 39.6 | 36.9 | 44.9 | 33.2 | C
6/4/2025 1:10:12 | 1:10:12 | 5s | 39.6 | 36.9 | 44.9 | 33.2 | C
6/4/2025 1:10:17 | 1:10:17 | 5s | 39.6 | 36.9 | 44.9 | 33.2 | C
6/4/2025 1:10:22 | 1:10:22 | 5s | 39.6 | 36.9 | 44.9 | 33.2 | C
6/4/2025 1:10:27 | 1:10:27 | 5s | 39.6 | 36.9 | 44.9 | 33.2 | C
6/4/2025 1:10:32 | 1:10:32 | 5s | 39.6 | 36.9 | 44.9 | 33.3 | C
6/4/2025 1:10:37 | 1:10:37 | 5s | 39.6 | 37 | 44.9 | 33.3 | C
6/4/2025 1:10:42 | 1:10:42 | 5s | 39.6 | 37 | 44.9 | 33.3 | C
6/4/2025 1:10:47 | 1:10:47 | 5s | 39.6 | 37 | 45 | 33.4 | C
6/4/2025 1:10:52 | 1:10:52 | 5s | 39.6 | 37 | 45 | 33.4 | C
6/4/2025 1:10:57 | 1:10:57 | 5s | 39.6 | 37 | 45 | 33.5 | C
6/4/2025 1:11:02 | 1:11:02 | 5s | 39.6 | 37 | 45 | 33.5 | C
6/4/2025 1:11:07 | 1:11:07 | 5s | 39.6 | 37 | 45 | 33.5 | C
6/4/2025 1:11:12 | 1:11:12 | 5s | 39.7 | 37 | 45 | 33.5 | C
6/4/2025 1:11:17 | 1:11:17 | 5s | 39.7 | 37 | 45 | 33.5 | C
6/4/2025 1:11:22 | 1:11:22 | 5s | 39.7 | 37 | 45 | 33.5 | C
6/4/2025 1:11:27 | 1:11:27 | 5s | 39.7 | 37 | 45 | 33.6 | C
6/4/2025 1:11:32 | 1:11:32 | 5s | 39.7 | 37 | 45 | 33.6 | C
6/4/2025 1:11:37 | 1:11:37 | 5s | 39.7 | 37 | 45.1 | 33.6 | C
6/4/2025 1:11:42 | 1:11:42 | 5s | 39.7 | 37 | 45.1 | 33.6 | C
6/4/2025 1:11:47 | 1:11:47 | 5s | 39.7 | 37 | 45.1 | 33.7 | C
6/4/2025 1:11:52 | 1:11:52 | 5s | 39.7 | 37 | 45.1 | 33.7 | C
6/4/2025 1:11:57 | 1:11:57 | 5s | 39.7 | 37 | 45.1 | 33.8 | C
6/4/2025 1:12:02 | 1:12:02 | 5s | 39.7 | 37 | 45.1 | 33.8 | C
6/4/2025 1:12:07 | 1:12:07 | 5s | 39.7 | 37 | 45.1 | 33.8 | C
6/4/2025 1:12:12 | 1:12:12 | 5s | 39.7 | 37.1 | 45.1 | 33.8 | C
6/4/2025 1:12:17 | 1:12:17 | 5s | 39.7 | 37.1 | 45.1 | 33.8 | C
6/4/2025 1:12:22 | 1:12:22 | 5s | 39.7 | 37.1 | 45.1 | 33.8 | C
6/4/2025 1:12:27 | 1:12:27 | 5s | 39.7 | 37.1 | 45.1 | 33.9 | C
6/4/2025 1:12:32 | 1:12:32 | 5s | 39.7 | 37.1 | 45.1 | 33.9 | C
6/4/2025 1:12:37 | 1:12:37 | 5s | 39.7 | 37.1 | 45.1 | 33.9 | C
6/4/2025 1:12:42 | 1:12:42 | 5s | 39.8 | 37.1 | 45.1 | 33.9 | C
6/4/2025 1:12:47 | 1:12:47 | 5s | 39.8 | 37.1 | 45.1 | 33.9 | C
6/4/2025 1:12:52 | 1:12:52 | 5s | 39.8 | 37.1 | 45.1 | 33.9 | C
6/4/2025 1:12:57 | 1:12:57 | 5s | 39.8 | 37.1 | 45.1 | 33.9 | C
6/4/2025 1:13:02 | 1:13:02 | 5s | 39.8 | 37.1 | 45.1 | 34.1 | C
6/4/2025 1:13:07 | 1:13:07 | 5s | 39.8 | 37.1 | 45.2 | 34.1 | C
6/4/2025 1:13:12 | 1:13:12 | 5s | 39.8 | 37.1 | 45.2 | 34.1 | C
6/4/2025 1:13:17 | 1:13:17 | 5s | 39.8 | 37.1 | 45.2 | 34.1 | C
6/4/2025 1:13:22 | 1:13:22 | 5s | 39.8 | 37.1 | 45.2 | 34.1 | C
6/4/2025 1:13:27 | 1:13:27 | 5s | 39.8 | 37.1 | 45.2 | 34.1 | C
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

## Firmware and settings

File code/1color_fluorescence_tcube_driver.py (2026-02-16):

import cv2, os, subprocess, time

#Download vmbpy from the manufacturer's repo: https://github.com/alliedvision/VmbPy
from vmbpy import *

#'board' will not import. Follow this guide to set up your system (Windows, Mac, or Linux) to be used with an FT232H board: https://learn.adafruit.com/circuitpython-on-any-computer-with-ft232h/setup
#You also need to set a environment variable called BLINKA_FT232H and set it to 1
#Windows Powershell: $env:BLINKA_FT232H = 1
#Linux export BLINKA_FT232H = 1
#Make sure the "I2C mode" switch on the FT232H board is set to ON
import board
import busio
import adafruit_mcp4725
i2c = busio.I2C(board.SCL, board.SDA)

#The address of your MCP4725 board might be different than mine. You can scan your system for i2c devices using this script from Adafruit: https://learn.adafruit.com/scanning-i2c-addresses/circuitpython
dac = adafruit_mcp4725.MCP4725(i2c, address=0x60)
dac.value=0
print("dac!")
     
#Set exposure time of the camera in seconds. vmbpy takes in us as the exposure value, so this is added for conversion convenience.
exposure_seconds = 1.5
EXPOSURE = exposure_seconds * 1000000

#Set gain here. Gain is measure in dB.
GAIN = 10

#Set where you want to save images to.
path = "YOUR_PATH_HERE/"

#LED intensity is stored as a 16-bit number. 32767 corresponds to 100% intensity.
LED_INTENSITY = 32767

#How often you want to wait between each image capture (in seconds)
SLEEP = 5

#Interface that allows Polulu Tic T825 commandline interface to be used in Python
def ticcmd(*args):
  return subprocess.check_output(['ticcmd'] + list(args))

#Counter variable for counting images taken.
i=0

#Function built on top of vmbpy for capturing single images.
def vimbagrab(path, i, cam):
    exposure_time = cam.ExposureTime
    exposure_time.set(EXPOSURE)
    cam.Gain.set(GAIN)
    tim = exposure_time.get()
    print("exposure is: " + str(tim/1000000)[0:4] + " seconds")
    dac.value=32767
    print("dac on")
    print(dac.value)
    frame = cam.get_frame(timeout_ms=(exposure_seconds*1000)+4)
    dac.value=0
    frame.convert_pixel_format(PixelFormat.Mono8)
    print(path+str(int(i))+'.png')
    cv2.imwrite(path+str(int(i))+'.png', frame.as_opencv_image())
    print("dac off")

#Initialize vmbpy camera. Make sure to close any open VimbaXViewer sessions before running the script or it will throw an error.
#All changes to imaging protocol need to go inside the while loop, since the camera is only initialized once. If you want to take a set number of images, change "while True" to some for loop.
#If you want to add position changes in Z while you capture images, add the command 'ticcmd('--exit-safe-start', '--position', str(YOUR_POSITION_NUMBER))' to move the motor to some specific spot.
#Use the ticgui software to find the Z value you want to image at, link: https://www.pololu.com/docs/0J71/3
with VmbSystem.get_instance() as vmb:
    cams = vmb.get_all_cameras()
    with cams[0] as cam:
        while True:

            vimbagrab(path, i, cam)
            
            i+=1

            time.sleep(SLEEP)

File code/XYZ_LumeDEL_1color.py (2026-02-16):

import time, os, serial
import cv2, subprocess, yaml, time, math
from datetime import datetime

#Download vmbpy from the manufacturer's repo: https://github.com/alliedvision/VmbPy
from vmbpy import *

#Set where you want to save images to.
writepath = "YOUR_PATH_HERE/"

#Replace these values with the ID associated with each Polulu Tic T825 Stepper Motor Driver you are using.
#Use the ticgui software to find these values, link: https://www.pololu.com/docs/0J71/3
mid_short = "MIDDLE_MOTOR_ID" #middle
mid_top = "TOP_MOTOR_ID" #top
mid_long = "BOTTOM_MOTOR_ID" #bottom

#Set exposure time of the camera in seconds. vmbpy takes in us as the exposure value, so this is added for conversion convenience.
exposure_seconds = 0.15
EXPOSURE = exposure_seconds * 1000000

#Set gain here. Gain is measure in dB.
gain = 10

#Counter variable for counting images taken.
cycle=0

#Set how intense you'd like the light to be using this value. It's a percentage.
INTENSITY = "100"

#On windows this will be a COM port, check Device Manager. Leave the serial settings as is.
PORT = "YOUR_PORT"

ser = serial.Serial(
    port=PORT,
    baudrate=115200,
    bytesize=serial.EIGHTBITS,
    parity=serial.PARITY_NONE,
    stopbits=serial.STOPBITS_ONE,
    timeout=1   
)

#Sets light intensity to 0.
#If you want to have the light intensity change in other parts of the code, use the command "ser.write(b"IX\r\n")", where X is some number between 0 and 100.
#LumeDEL LED reference is in the manual, link: https://lumedel.com/lumedel-downloads/
ser.write(b"I0\r\n")

#Interface that allows Polulu Tic T825 commandline interface to be used in Python
def ticcmd(*args):
    return subprocess.check_output(['ticcmd'] + list(args))

#Deenergizes the Polulu Tic T825 associated with the passed ID.
def deenergize(mid):
    print("Deenergizing")
    ticcmd('--deenergize', '-d', mid)

#Energizes the Polulu Tic T825 associated with the passed ID.
def energize(mid):
    print("Energizing")
    ticcmd('--energize', '--exit-safe-start', '-d', mid)

#Zeroes the Polulu Tic T825 associated with the passed ID if endstop has been configured.
def zerostage(mid):
    ticcmd('--exit-safe-start', '--home', 'rev', '-d', mid)
    return

#Moves the Polulu Tic T825 associated with the passed ID by relativepos steps. Relativepos can be positive or negative.
def move(mid, relativepos):
    if(relativepos!=0):
        status = yaml.load(ticcmd('-s', '--full', '-d', mid), Loader=yaml.Loader)
        position = status['Current position']
        print("Current position is {}.".format(position))
        new_target = position+relativepos
        
        print("Setting target position to {}.".format(new_target))
        ticcmd('--exit-safe-start', '--position', str(new_target), '-d', mid)
        #time.sleep(abs(relativepos)/100+5)
    return

#Moves the Polulu Tic T825 associated with the passed ID to the specified position.
def moveabs(mid,pos):
    ticcmd('--exit-safe-start', '--position', str(pos), '-d', mid)
    return

#Function built on top of vmbpy for capturing single images.
def vimbagrab(path, i, cam):
    exposure_time = cam.ExposureTime
    exposure_time.set(EXPOSURE)
    cam.Gain.set(gain)
    timet = exposure_time.get()
    print("exposure is: " + str(timet/1000000)[0:4] + " seconds")
    ser.write(b"I"+INTENSITY+"\r\n")
    time.sleep(1)
    frame = cam.get_frame()
    frame.convert_pixel_format(PixelFormat.Mono8)
    ser.write(b"I0\r\n")
    print(path+'.png')
    cv2.imwrite(path+'.png', frame.as_opencv_image())

with VmbSystem.get_instance() as vmb:
    cams = vmb.get_all_cameras()
    with cams[0] as cam:
        while True:
            #Implement your scanning protocol here.
            #Example which turns the motors on, zeroes, them, moves to 1000,1000,1000 and takes a picture.

            '''
            energize(mid_top)
            energize(mid_short)
            energize(mid_long)
            
            zerostage(mid_top)
            time.sleep(30)
            zerostage(mid_short)
            time.sleep(30)
            zerostage(mid_long)
            time.sleep(30)

            moveabs(mid_long, 1000)
            time.sleep(30)
            moveabs(mid_short, 1000)
            time.sleep(30)
            moveabs(mid_top, 1000)
            time.sleep(30)

            path = writepath + str(cycle) + "/" testimage
            try:
                vimbagrab(path, cycle, cam)
            except Exception as e:
                print(e)
            time.sleep(2)
            
            cycle+=1
            zerostage(mid_top)
            deenergize(mid_short)
            deenergize(mid_top)
            deenergize(mid_long)
            time.sleep(60)
            '''

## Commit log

2025-06-12 Update and rename Thermal validation - Sheet1.csv to Thermalvalidationdata.csv
    [Thermalvalidationdata.csv]
2025-06-12 Update and rename C-I428W425120A_beamsplitter rotary inner.stp to beamsplitter_rotary_inner.stp
    [beamsplitter_rotary_inner.stp]
2025-06-12 Update and rename C-I429W425120A_rotator to c-mount.stp to rotator_to_c-mount.stp
    [rotator_to_c-mount.stp]
2025-06-12 Update and rename C-I430W425120A_beamsplitter rotary outer.stp to beamsplitter_rotary_outer.stp
    [beamsplitter_rotary_outer.stp]
2025-06-12 Update and rename C-I431W425120A_rotary filter barrel bottom.stp to rotary_filter_barrel_bottom.stp
    [rotary_filter_barrel_bottom.stp]
2026-02-16 adding flatparts post supplemental completion
    [bigbase_xyz.dxf, cam_to_turner_servo.dwg, endstop_hitter_long_xyz.dxf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]
